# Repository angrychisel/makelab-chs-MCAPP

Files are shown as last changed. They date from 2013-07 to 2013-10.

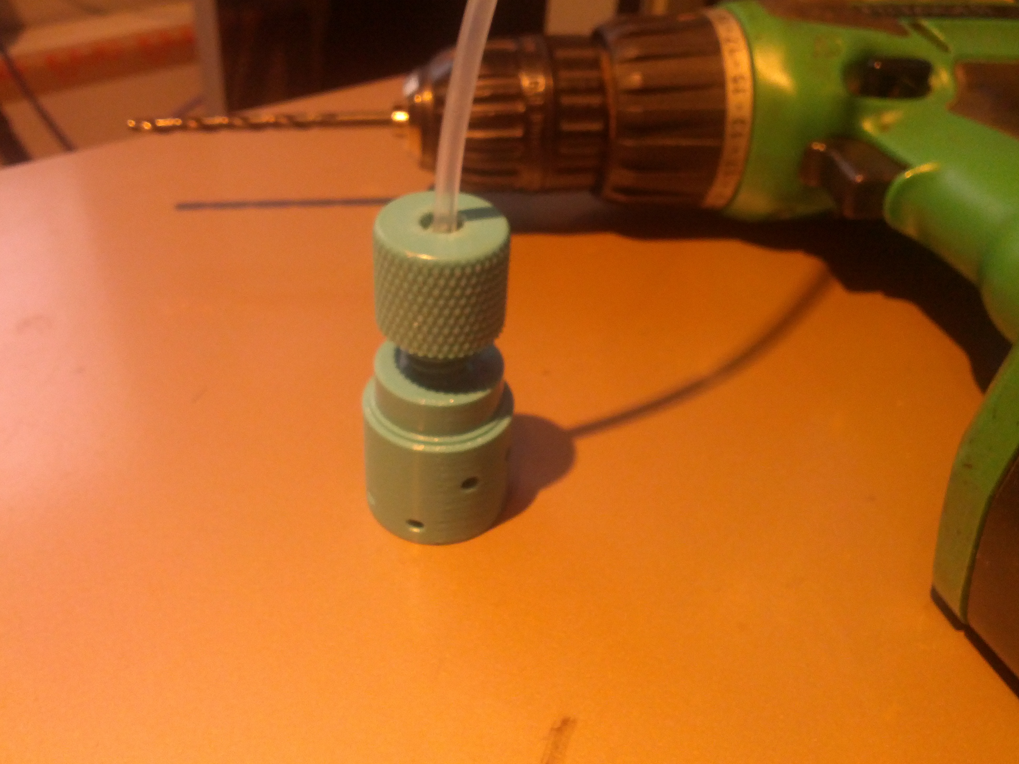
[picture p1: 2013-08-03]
MORGAN/IMAGES/2013-07-31 16.58.30.jpg

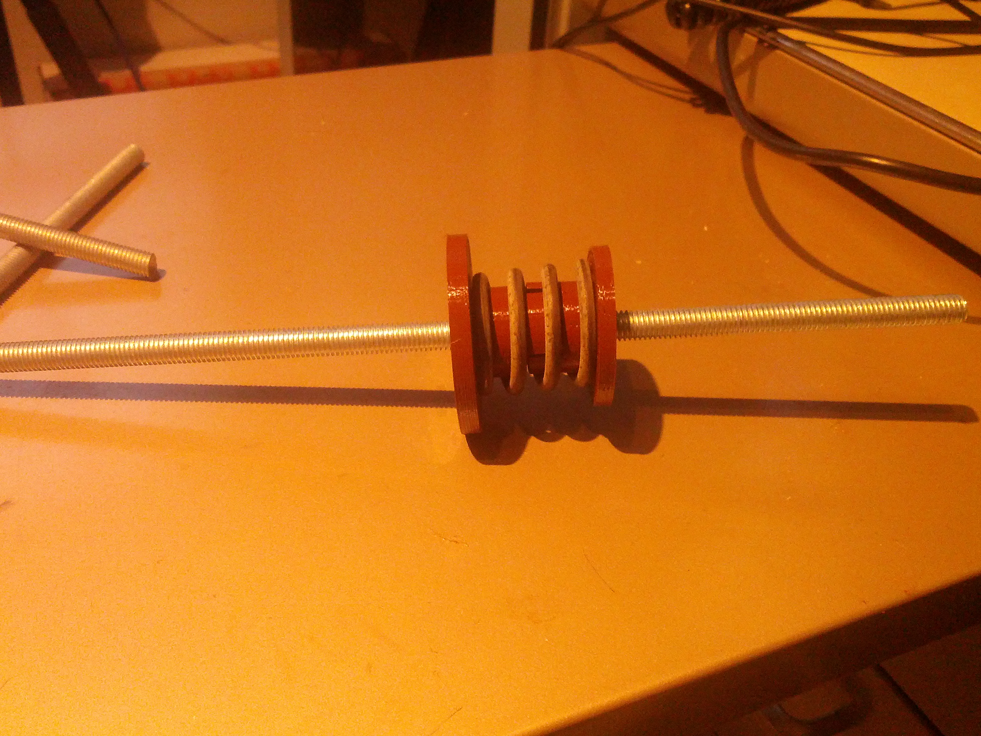
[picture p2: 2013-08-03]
MORGAN/IMAGES/2013-07-31 17.22.46.jpg

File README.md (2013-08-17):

Visit our IRC channel (http://makelabcharleston.org/)

MCAPP - The Makelab Charleston Affordable 3d Printer Project
----------------------

[[Github Page](http://angrychisel.github.io/makelab-chs-MCAPP/)]

**Join our IRC Channel**

Visit our IRC channel (https://kiwiirc.com/client/irc.freenode.net/?nick=morgan|?#makelabcharleston)

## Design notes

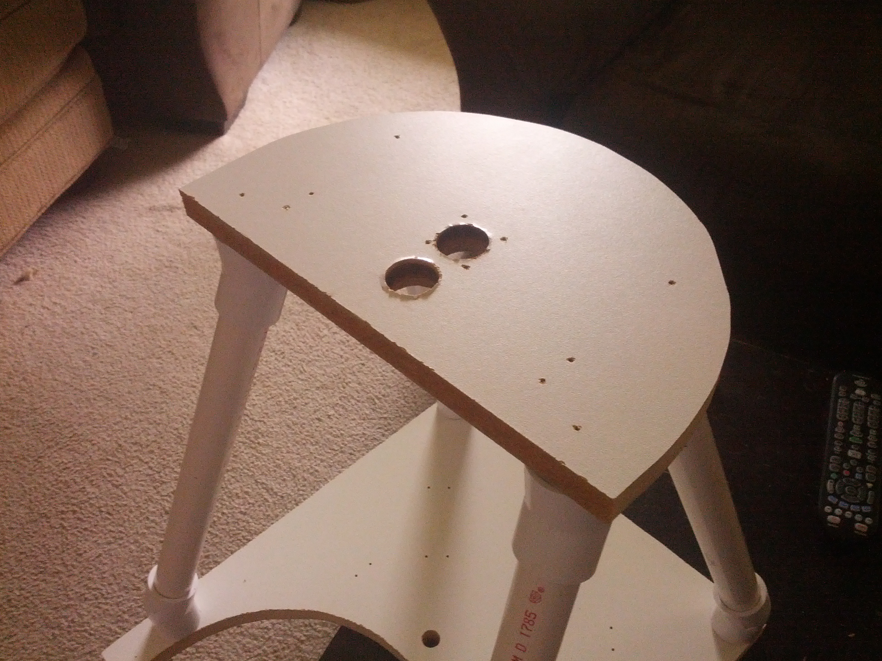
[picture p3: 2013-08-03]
MORGAN/IMAGES/2013-08-03 15.07.26.jpg

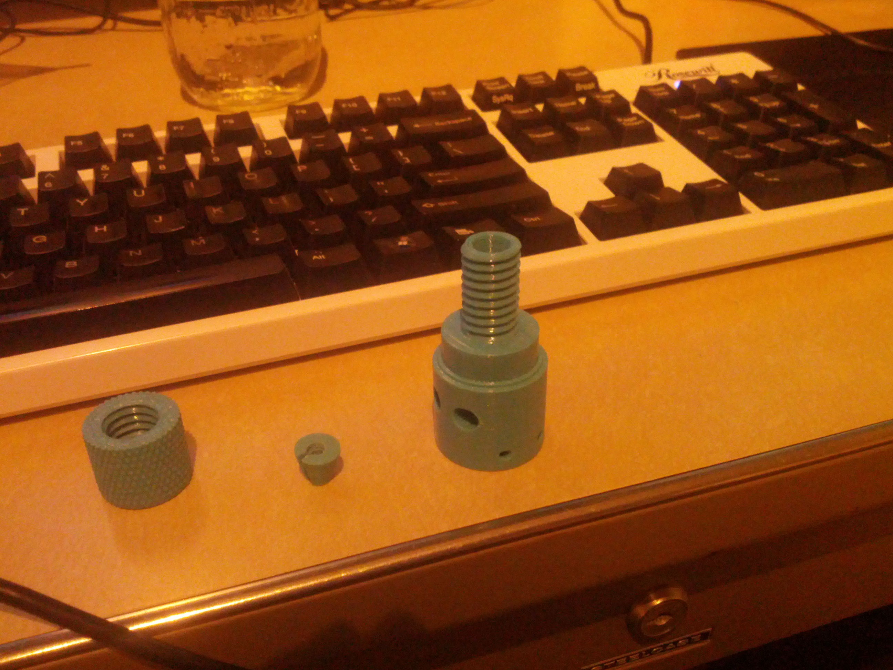
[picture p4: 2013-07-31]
MORGAN/IMAGES/2013-07-30 22.39.01.jpg

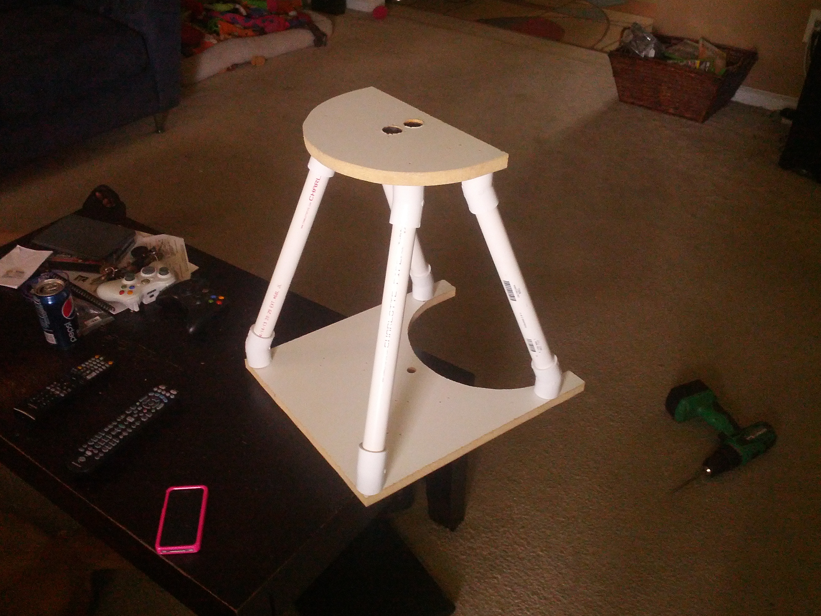
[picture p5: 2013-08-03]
MORGAN/IMAGES/2013-08-03 15.07.51.jpg

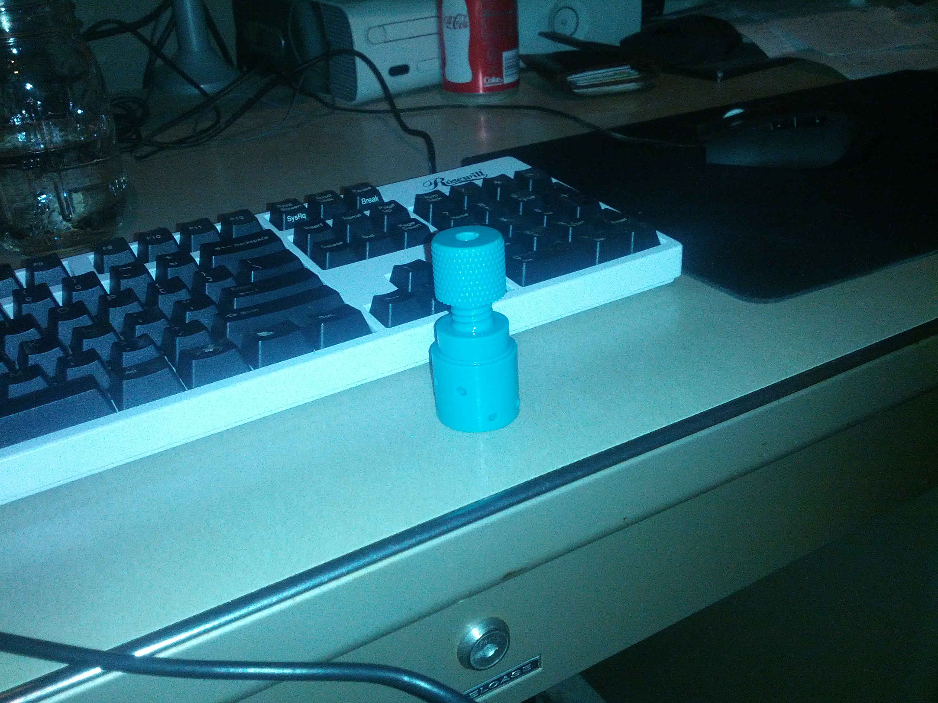
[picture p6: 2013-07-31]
MORGAN/IMAGES/2013-07-30 22.37.41.jpg

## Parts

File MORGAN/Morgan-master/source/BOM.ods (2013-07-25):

Component | Quantity
01-pvc_pipe_support_a | 4
02-pvc_pipe_support_b | 4
03-z_mount_bottom_8mm | 1
04-z_mount_top_8mm | 1
05-motormount_short | 1
06-motormount_tall | 1
07-drivewheel_rod | 1
08-drivewheel_tube | 1
09-22mm_6805_bearing_adaptor | 1
10-bed_arm_left_8mm | 1
11-bed_arm_right_8mm | 1
12-bed_z_mount_bracket | 1
13-bed_rear_mountclips | 2
15mm pipe holders – To be done | 2
15-hall_endstop_holder | 3
16-leadscrew_shaft_motor_mount | 1
17-Morgan_arm_PSI_a | 1
18-Morgan_arm_PSI_b | 1
19-Morgan_arm_Theta_a | 1
20-Morgan_arm_Theta_b | 1
21-Morgan_toolhead | 1
22-Leadscrew-nut_Alpen8mmSDS | 1
23-extruder_bowden_adaptor | 1
Cap_2 | 2
Eckstruder_Big_Gear_Herringbone | 1
Eckstruder_Block_for_Prusa | 1
Eckstruder_Idler_Block_for_Prusa | 1
Eckstruder_Small_Gear_Herrinbone | 1
thumb_knob_M4_extruder | 1
TighteningCone_2 | 2
M8 nut | 12
M8 washer | 6
M8 spring washer | 10
M8 washer 28mm | 6
M4 nut | 9
M4 bolt 40mm | 8
M4 bolt 80mm | 1
M8 Nylock Nut | 6
M8 Bolt 40mm | 3
M8 Bolt 100mm | 1
M8 Bolt 60mm | 1
PVC pipe 32mm OD 459mm | 2
PVC pipe 32mm OD 452mm | 2
2mm self tapping coach screws, 40mm | 2
15mm brass pipe 440mm | 1
15mm brass pipe 200mm | 2
22mm brass pipe 460mm | 1
8mm threaded rod 650mm | 1
8mm smooth rod | 2
608z | 5
F608z | 4
hard spring (idler compression) 7mm | 1
8mm soft spring (lead screw anti backlash | 1
cabinet coach screws, 5mm | 10
LM8uu bearing or alternative | 4
lead screw 330mm | 1
M3 nut | 3
M3 grub screw 6mm (or suitable replacement bolt | 3
hall effect endstop sensors | 3
Electronics | 1
Pololu low current 1/16th | 2
Pololu high current 1/32th | 2
Step motor 200step (1.8deg) | 2
Step motor 400step (0.9deg (if possible – otherwise increase other motors) | 2
Power supply AXT 400W minimum | 1
PTFE tube 6mm 600mm | 1
Additional PTFE tube 4mm 600mm (Only if 1.75mm J-head) | 1
Morgan lasercut platforms | 1
Universal build plate | 1
Mk2a heatbed | 1
aluminium build surface | 1
Ethernet cable, multistrand flexible, m | 5
High current cable, heatbed m | 1

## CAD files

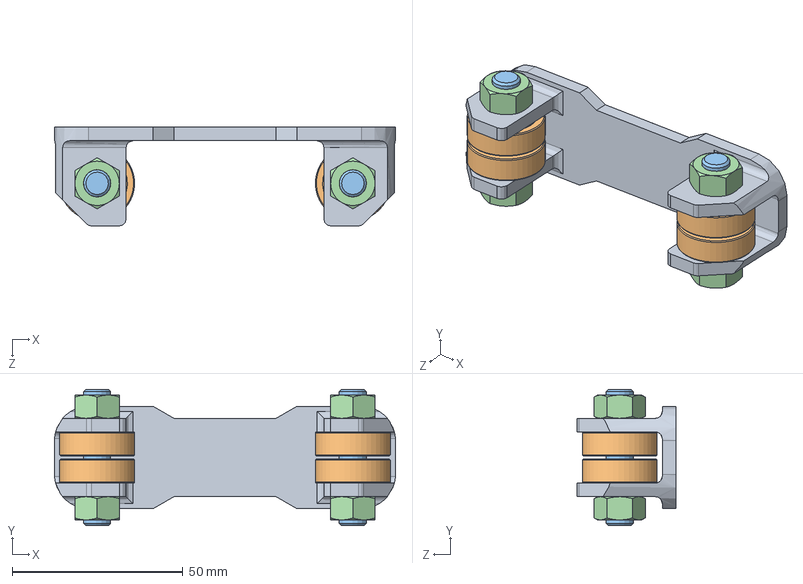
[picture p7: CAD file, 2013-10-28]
MORGAN/ACCESSORIES/SPOOL ROLLER ASSY.SLDASM
100.0 x 40.0 x 29.0 mm
SPOOL ROLLER
radial ball bearing_68_am x 4
continous stud_am x 2
hex nut style 1_am x 4

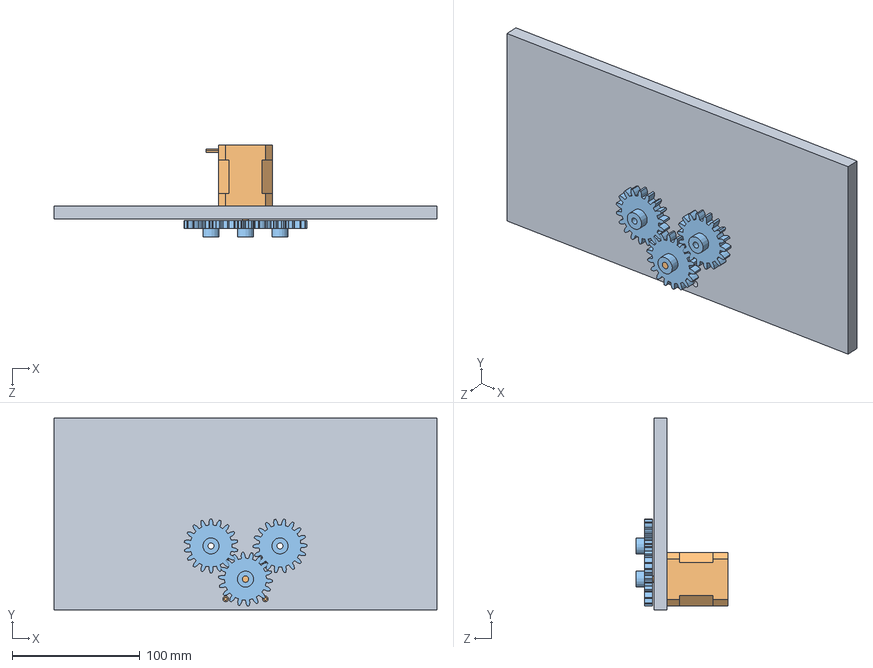
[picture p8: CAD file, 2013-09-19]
MORGAN/good extruder/good extruder assy.SLDASM
300.0 x 150.0 x 71.8 mm
main plate
NEMA17STEPPER
spur gear_ai x 3
radial ball bearing_68_am x 2

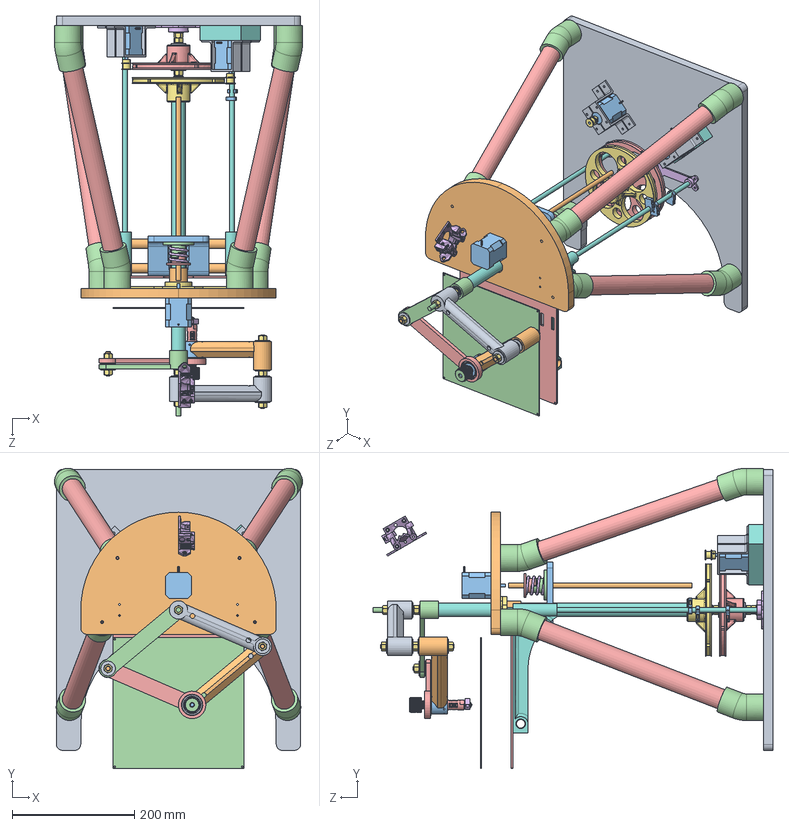
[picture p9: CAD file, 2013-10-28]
MORGAN/MLC-1.SLDASM
406.1 x 491.9 x 655.0 mm
MLC-1-001
MLC-1-002
NEMA17STEPPER x 3
4880K703 x 8
MLC-1-004 x 4
MLC-1-005
MLC-1-006
MLC-1-0012 x 2
LM8UU x 4
MLC-1-0015 x 3
MLC-1-0021
MLCE-1-001
MLCE-1-002
9662K350
hex nut style 1_am x 2
MLC-1-0014 x 2
radial ball bearing_68_skf x 8
MLC-1-0022
MLC-1-0025 x 8
MLC-1-008
MLC-1-0010
MLC-1-0026
MLC-1-009
MLC-1-007
MLC-1-0016
MLC-1-0017
MLC-1-0018
MLC-1-0019
MLC-1-0020
curved spring lock washer_din x 6
hex nut gradec_din x 22
plain washer 6902 type abc_din x 5
plain washer large_din x 9
continous stud_am x 2
socket head cap screw_am x 2
MLC-1-030
JHEAD
JHEAD NOZZLE
pulley 20t gt2 2mm x 2
MLC-1-0027
MLC-1-0028 x 4
MLC-1-0029
hall_effect_sensor_holder x 3
MK2A Heatbed
HEATBED BASE PLATE
airtripper-extruder-v3

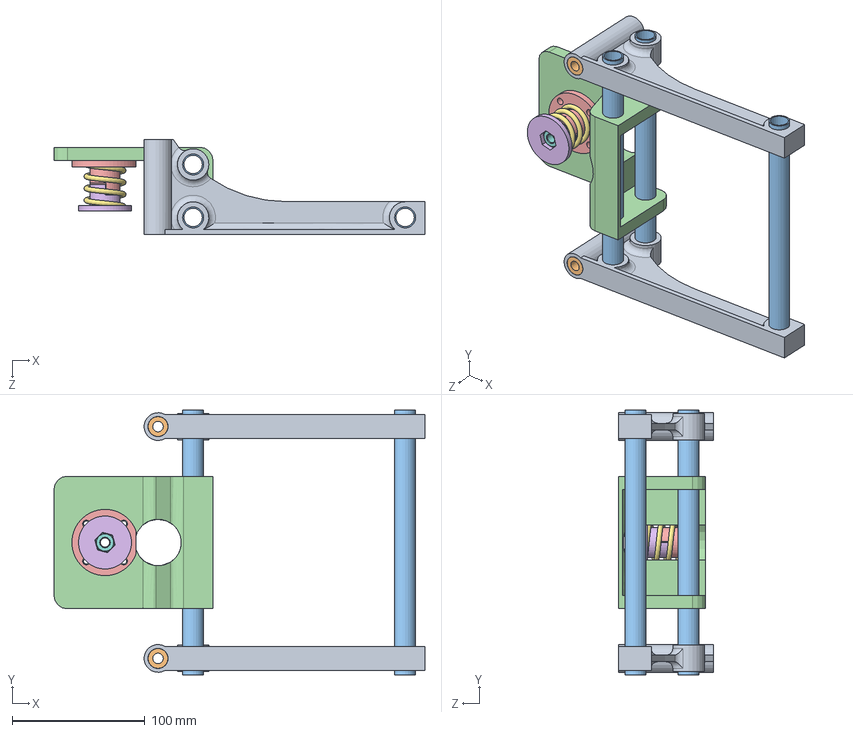
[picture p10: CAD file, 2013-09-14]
MORGAN/MLC-3.SLDASM
280.0 x 200.0 x 72.0 mm
MLC-1-0012 x 2
LM8UU x 4
MLC-1-0015 x 3
MLC-1-0021
MLCE-1-001
MLCE-1-002
9662K350
hex nut style 1_am x 2

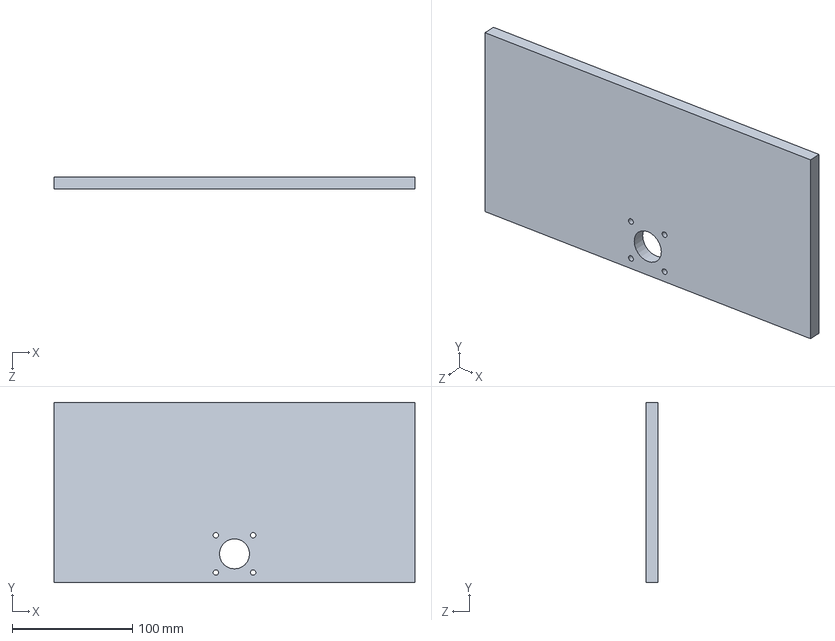
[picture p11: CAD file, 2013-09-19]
MORGAN/good extruder/main plate.SLDPRT
300.0 x 150.0 x 10.0 mm

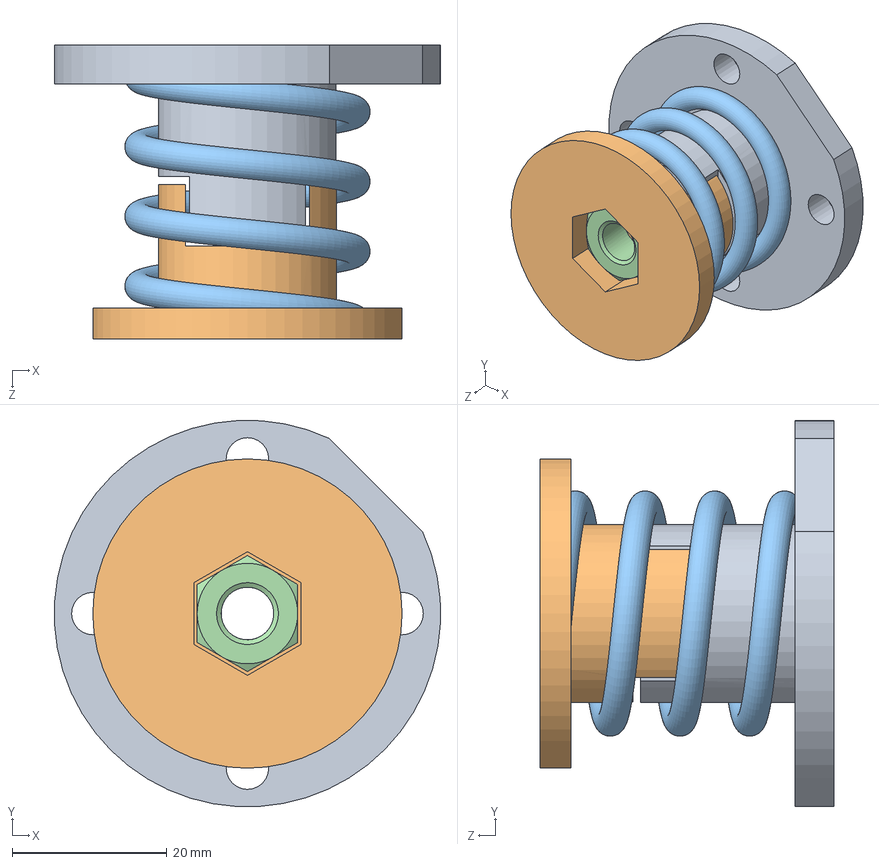
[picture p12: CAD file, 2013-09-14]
MORGAN/EXPERIMENTAL/MLCE-50.SLDASM
49.9 x 49.9 x 38.0 mm
MLCE-1-001
MLCE-1-002
9662K350
hex nut style 1_am x 2

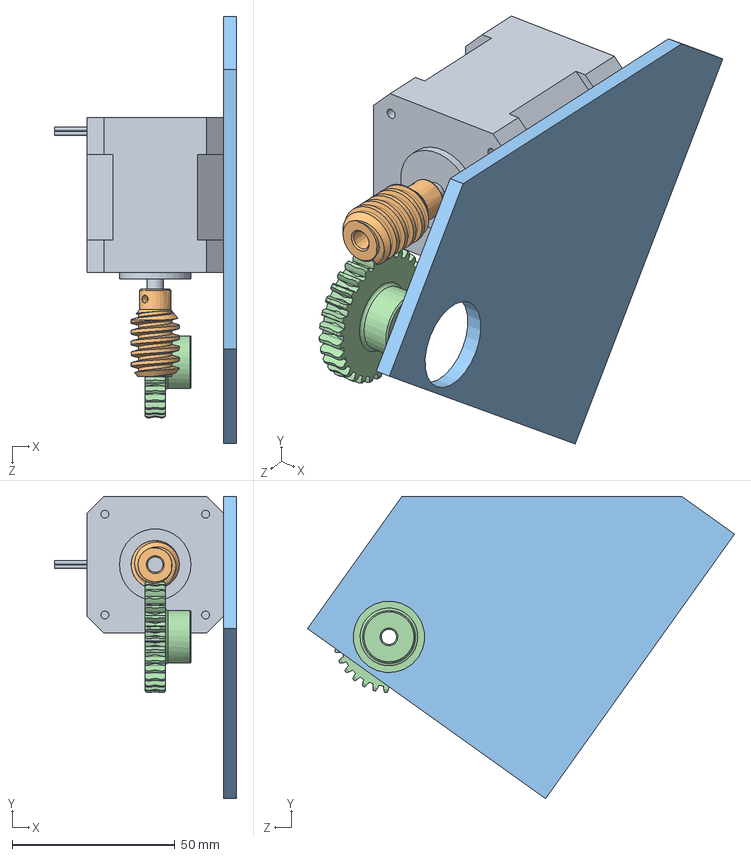
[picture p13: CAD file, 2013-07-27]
MORGAN/WORM EXTRUDER/MLCEX-1.SLDASM
56.0 x 93.0 x 131.4 mm
NEMA17STEPPER
LUHB
STEPPER BASE
g1035

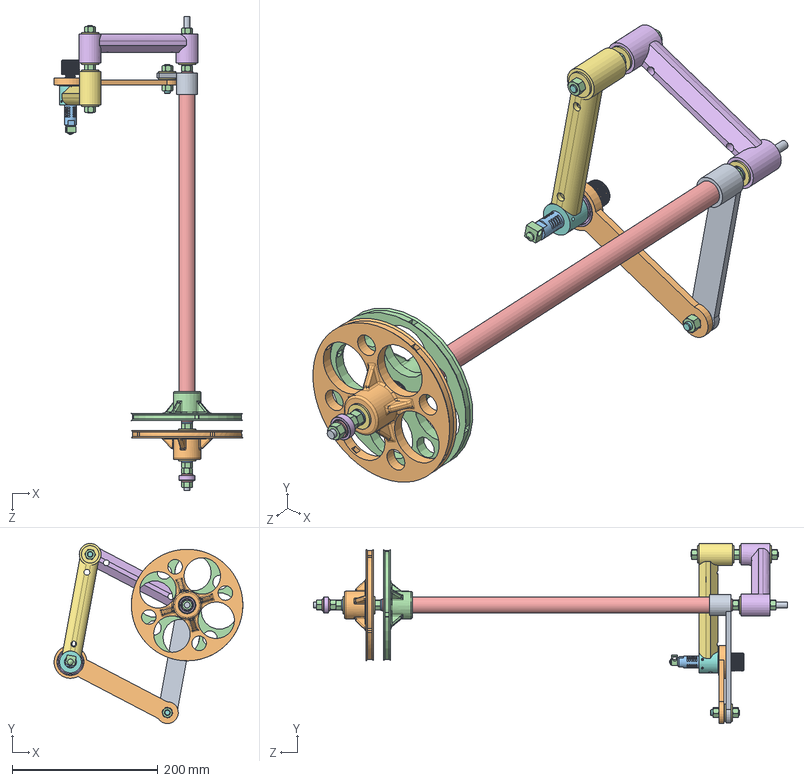
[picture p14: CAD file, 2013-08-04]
MORGAN/MLC-6.SLDASM
258.9 x 247.0 x 650.0 mm
MLC-1-008
MLC-1-0010
MLC-1-0026
MLC-1-009
MLC-1-007
MLC-1-0016
MLC-1-0017
MLC-1-0018
MLC-1-0019
MLC-1-0020
curved spring lock washer_din x 6
hex nut gradec_din x 22
plain washer 6902 type abc_din x 5
radial ball bearing_68_skf x 7
plain washer large_din x 9
continous stud_am x 2
socket head cap screw_am x 2
MLC-1-030
JHEAD
JHEAD NOZZLE

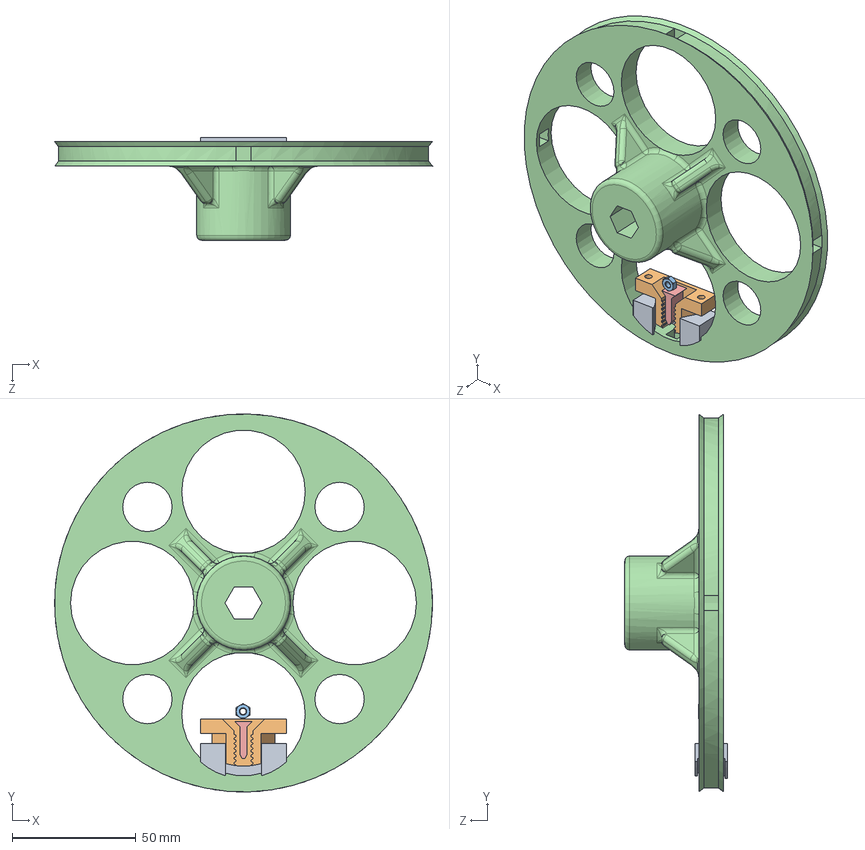
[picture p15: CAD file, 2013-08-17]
MORGAN/EXPERIMENTAL/belt tenisoner.SLDASM
153.0 x 152.9 x 41.5 mm
belt tensioner bottom
belt tensioner
hex nut style 1_am
MLC-1-0010
belt stop

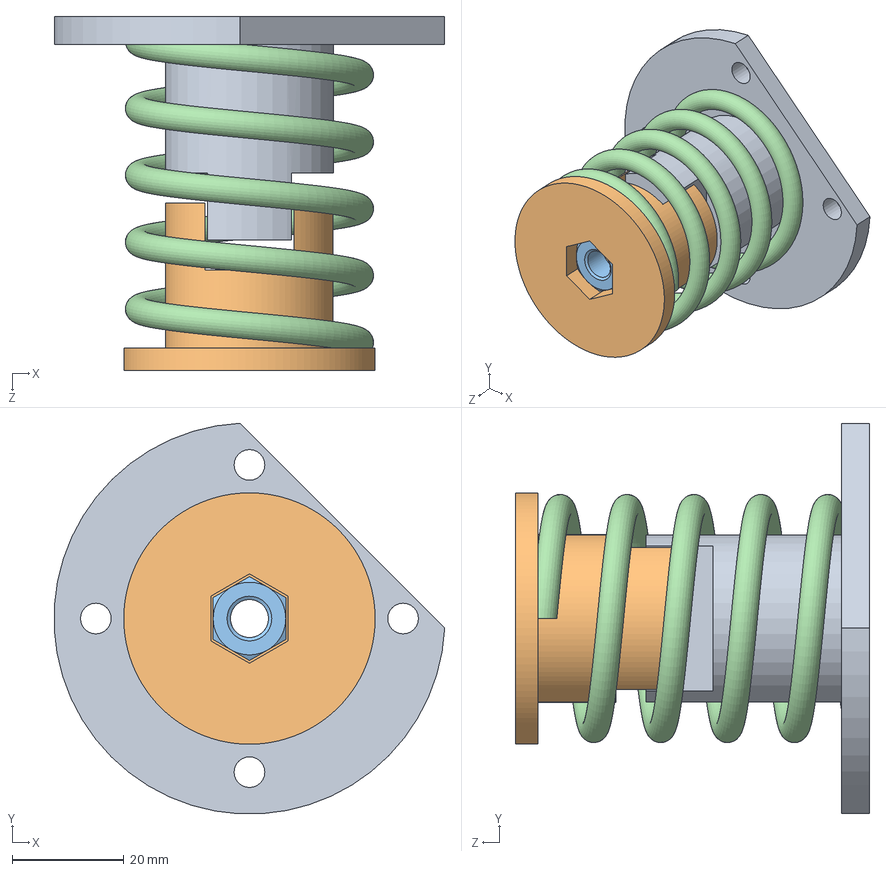
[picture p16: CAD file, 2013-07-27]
MORGAN/EXPERIMENTAL/MLC-5.SLDASM
69.9 x 69.9 x 63.4 mm
MLC-1-024
MLC-1-023
hex nut style 1_am x 2
9662K480

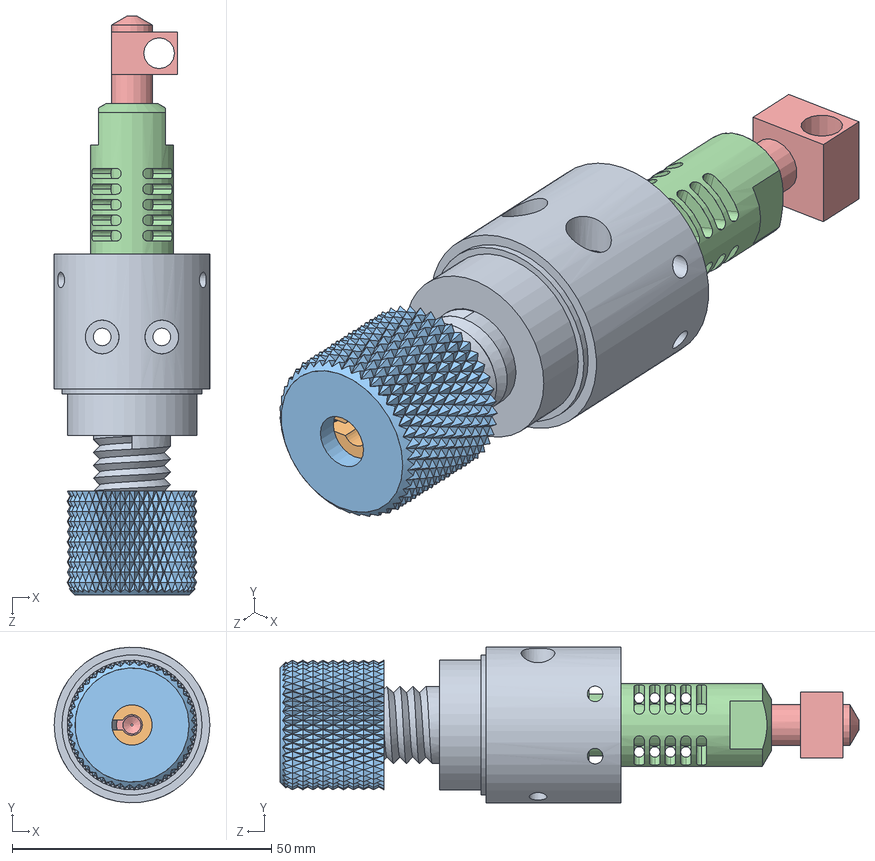
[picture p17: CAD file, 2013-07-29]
MORGAN/MLC-7.SLDASM
30.0 x 30.0 x 111.6 mm
MLC-1-0018
MLC-1-031
MLC-1-030
JHEAD
JHEAD NOZZLE

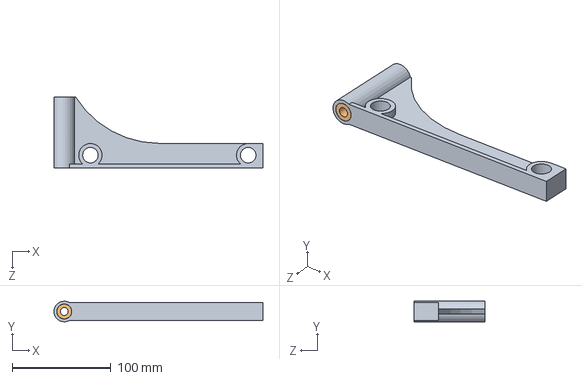
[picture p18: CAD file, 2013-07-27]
MORGAN/MLC-2.SLDASM
211.9 x 21.0 x 72.0 mm
MLC-1-0012
LM8UU x 2

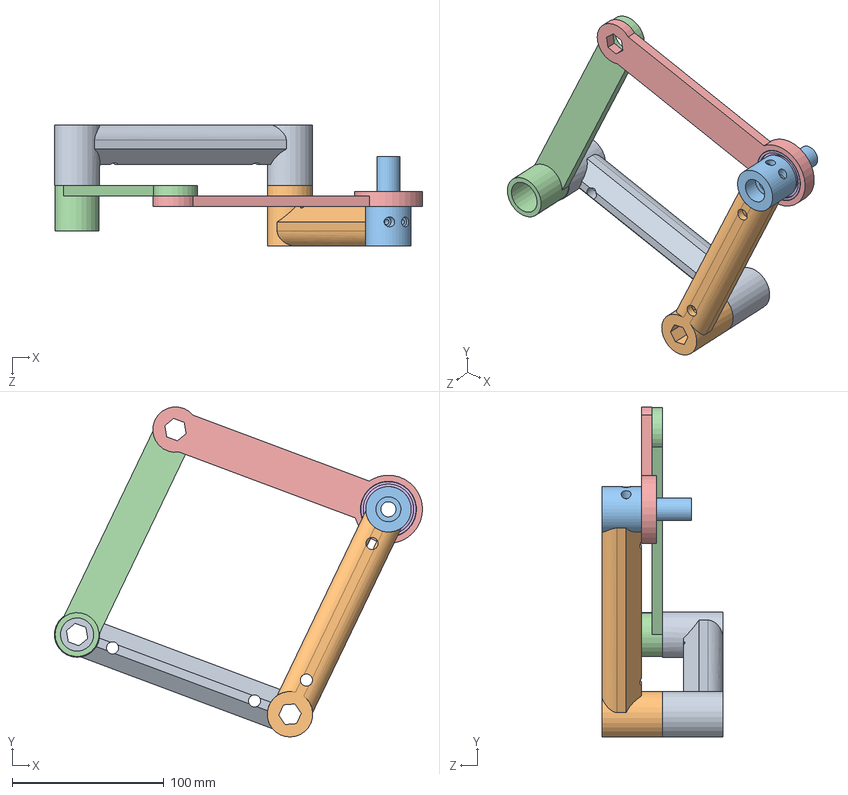
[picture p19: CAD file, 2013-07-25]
MORGAN/MLC-4.SLDASM
242.8 x 217.7 x 80.0 mm
MLC-1-0016
MLC-1-0017
MLC-1-0018
MLC-1-0019
MLC-1-0020
radial ball bearing_68_skf

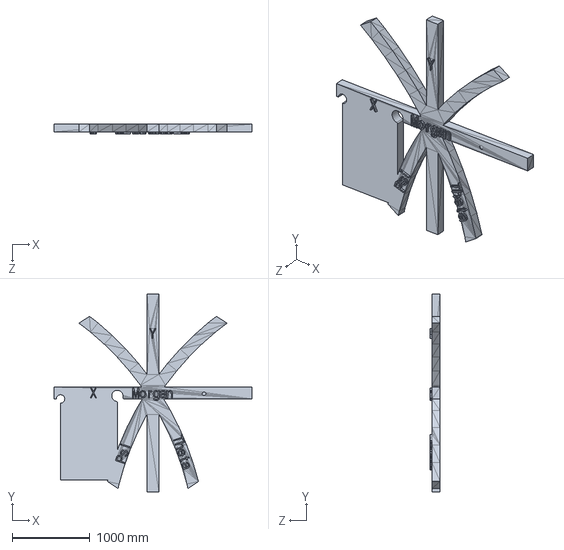
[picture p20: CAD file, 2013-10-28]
MORGAN/EXPERIMENTAL/SCARA-CAL.SLDPRT
2540.0 x 2540.0 x 127.0 mm

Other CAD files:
MORGAN/FAB APPROVED STL/MLC-1-0029.STL
MORGAN/Morgan-master/dxf/UNIVERSAL PLATE.SLDPRT
MORGAN/Morgan-master/source/Base_and_Riser_2.stl
MORGAN/Morgan-master/stl/NEMA17STEPPER.SLDPRT
MORGAN/EXPERIMENTAL/SCARA-CAL.scad
MORGAN/Morgan-master/source/Reprap_Morgan-v1.00.scad
MORGAN/4880K330.SLDPRT
MORGAN/4880K703.SLDPRT
MORGAN/ACCESSORIES/SPOOL ROLLER.SLDPRT
MORGAN/ACCESSORIES/SPOOL ROLLER.STL
MORGAN/EXPERIMENTAL/50mm riser-short.SLDPRT
MORGAN/EXPERIMENTAL/50mm riser.SLDPRT
MORGAN/EXPERIMENTAL/9662K350.SLDPRT
MORGAN/EXPERIMENTAL/9662K480.SLDPRT
MORGAN/EXPERIMENTAL/HEATBED BASE PLATE.DXF
MORGAN/EXPERIMENTAL/HEATBED BASE PLATE.SLDDRW
MORGAN/EXPERIMENTAL/HEATBED BASE PLATE.SLDPRT
MORGAN/EXPERIMENTAL/MLC-1-023.SLDPRT
MORGAN/EXPERIMENTAL/MLC-1-023.STL
MORGAN/EXPERIMENTAL/MLC-1-024.SLDPRT
MORGAN/EXPERIMENTAL/MLC-1-024.STL
MORGAN/EXPERIMENTAL/MLCE-1-001.SLDDRW
MORGAN/EXPERIMENTAL/MLCE-1-001.SLDPRT
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

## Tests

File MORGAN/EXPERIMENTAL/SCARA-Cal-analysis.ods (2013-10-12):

Dimension | Measurement | Target | Current Step/deg | Scaling Factor | New Step M92 | New factor M365 | after scaling
Theta | 100 | 100.000 | 450 |  | 450 | 1 | 100.000
Psi | 100 | 100.000 | 450 |  | 450 | 1 | 100.000
X | 100 | 100.000 |  | 1 |  | 1 | 100.000
Y | 100 | 100.000 |  | 1 |  | 1 | 100.000
Z

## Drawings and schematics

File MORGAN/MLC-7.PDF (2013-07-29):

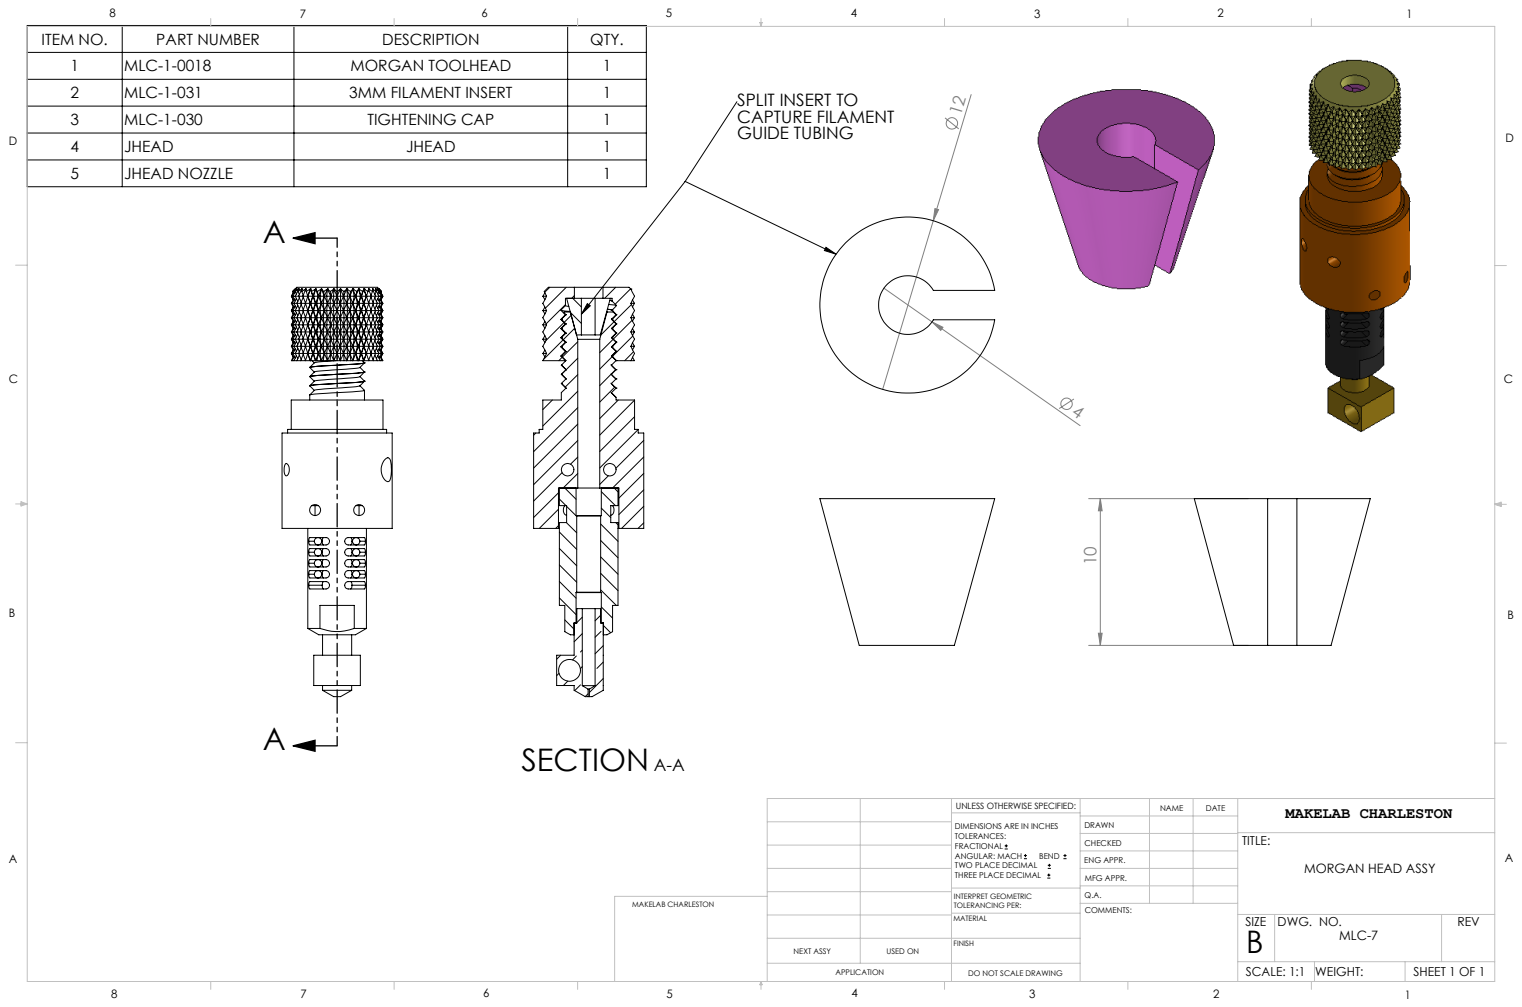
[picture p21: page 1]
SECTION A-A; MAKELAB CHARLESTON; NEXT ASSY; USED ON; ANGULAR: MACH; BEND; INTERPRET GEOMETRIC TOLERANCING PER:; ENG APPR.; MFG APPR.; NAME; DATE; DWG. NO.; REV; SCALE: 1:1 WEIGHT:; SHEET 1 OF 1

ITEM NO. | PART NUMBER | DESCRIPTION | QTY.
1 | MLC-1-0018 | MORGAN TOOLHEAD | 1
2 | MLC-1-031 | 3MM FILAMENT INSERT | 1
3 | MLC-1-030 | TIGHTENING CAP | 1
4 | JHEAD | JHEAD | 1
5 | JHEAD NOZZLE | | 1

SPLIT INSERT TO
CAPTURE FILAMENT
GUIDE TUBING

UNLESS OTHERWISE SPECIFIED:

DIMENSIONS ARE IN INCHES
TOLERANCES:
FRACTIONAL
TWO PLACE DECIMAL
THREE PLACE DECIMAL

MORGAN HEAD ASSY

DO NOT SCALE DRAWING

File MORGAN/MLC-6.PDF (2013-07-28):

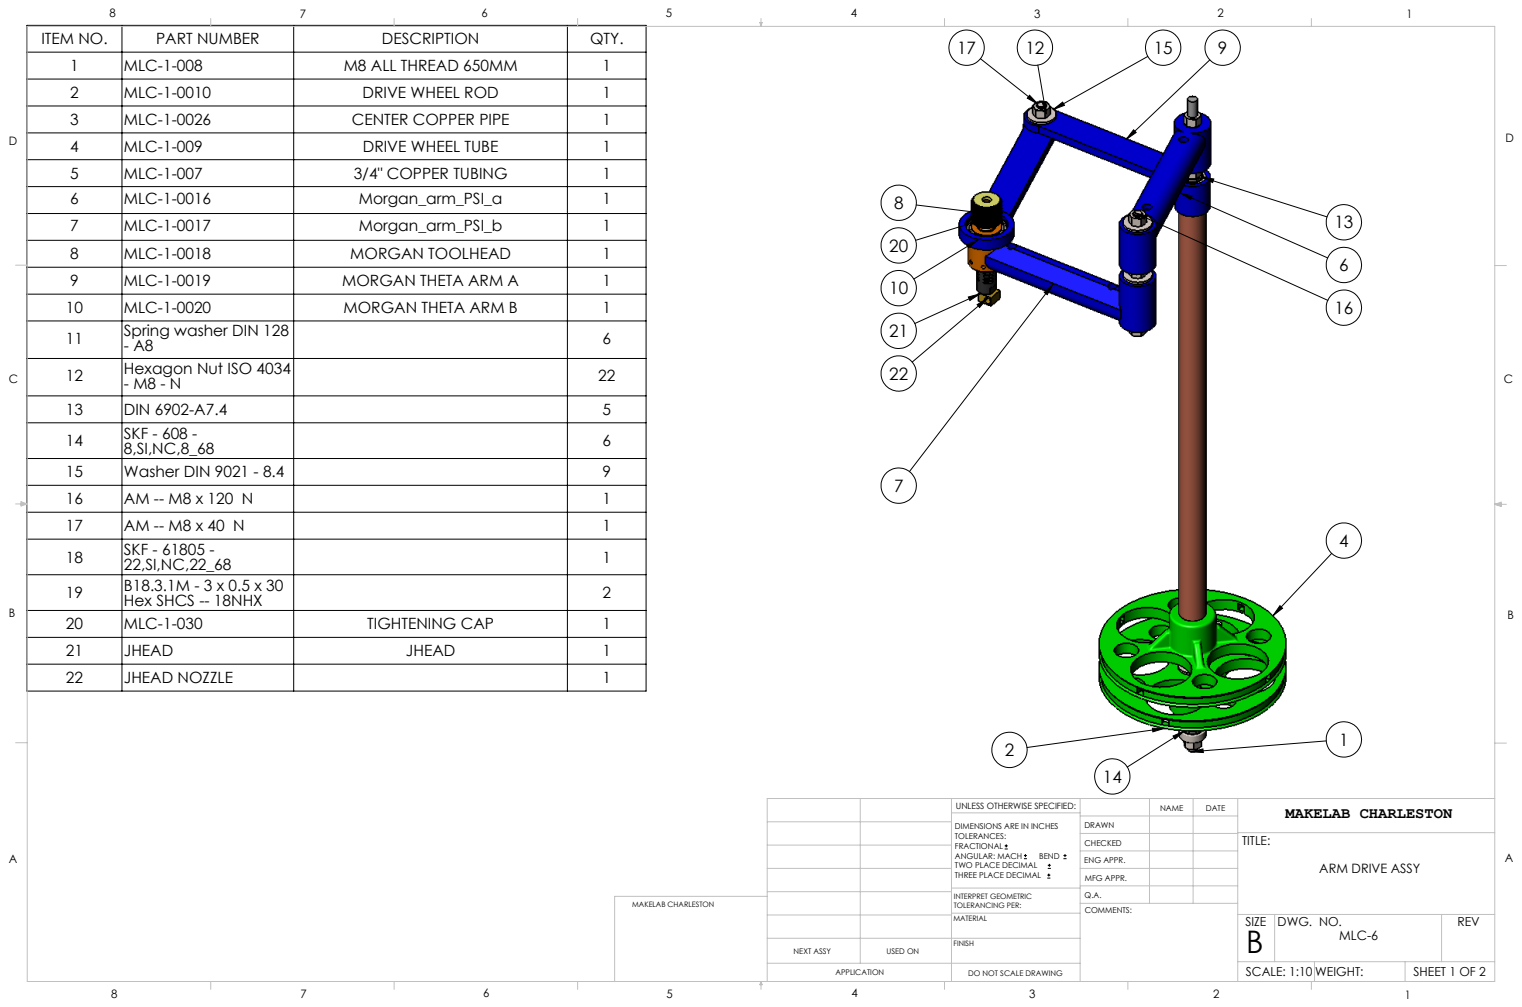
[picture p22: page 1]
MAKELAB CHARLESTON; NEXT ASSY; USED ON; ANGULAR: MACH; BEND; INTERPRET GEOMETRIC TOLERANCING PER:; ENG APPR.; MFG APPR.; NAME; DATE; DWG. NO.; REV; SCALE: 1:10 WEIGHT:; SHEET 1 OF 2

ITEM NO. | PART NUMBER | DESCRIPTION | QTY.
1 | MLC-1-008 | M8 ALL THREAD 650MM | 1
2 | MLC-1-0010 | DRIVE WHEEL ROD | 1
3 | MLC-1-0026 | CENTER COPPER PIPE | 1
4 | MLC-1-009 | DRIVE WHEEL TUBE | 1
5 | MLC-1-007 | 3/4" COPPER TUBING | 1
6 | MLC-1-0016 | Morgan_arm_PSI_a | 1
7 | MLC-1-0017 | Morgan_arm_PSI_b | 1
8 | MLC-1-0018 | MORGAN TOOLHEAD | 1
9 | MLC-1-0019 | MORGAN THETA ARM A | 1
10 | MLC-1-0020 | MORGAN THETA ARM B | 1
11 | Spring washer DIN 128 - A8 | | 6
12 | Hexagon Nut ISO 4034 - M8 - N | | 22

13 | DIN 6902-A7.4 | | 5
14 | SKF - 608 -8,SI,NC,8_68 | | 6
15 | Washer DIN 9021 - 8.4 | | 9
16 | AM -- M8 x 120 N | | 1
17 | AM -- M8 x 40 N | | 1
18 | SKF - 61805 -22,SI,NC,22_68 | | 1
19 | B18.3.1M - 3 x 0.5 x 30 Hex SHCS -- 18NHX | | 2
20 | MLC-1-030 | TIGHTENING CAP | 1
21 | JHEAD | JHEAD | 1
22 | JHEAD NOZZLE | | 1

UNLESS OTHERWISE SPECIFIED:

DIMENSIONS ARE IN INCHES
TOLERANCES:
FRACTIONAL
TWO PLACE DECIMAL
THREE PLACE DECIMAL

ARM DRIVE ASSY

DO NOT SCALE DRAWING

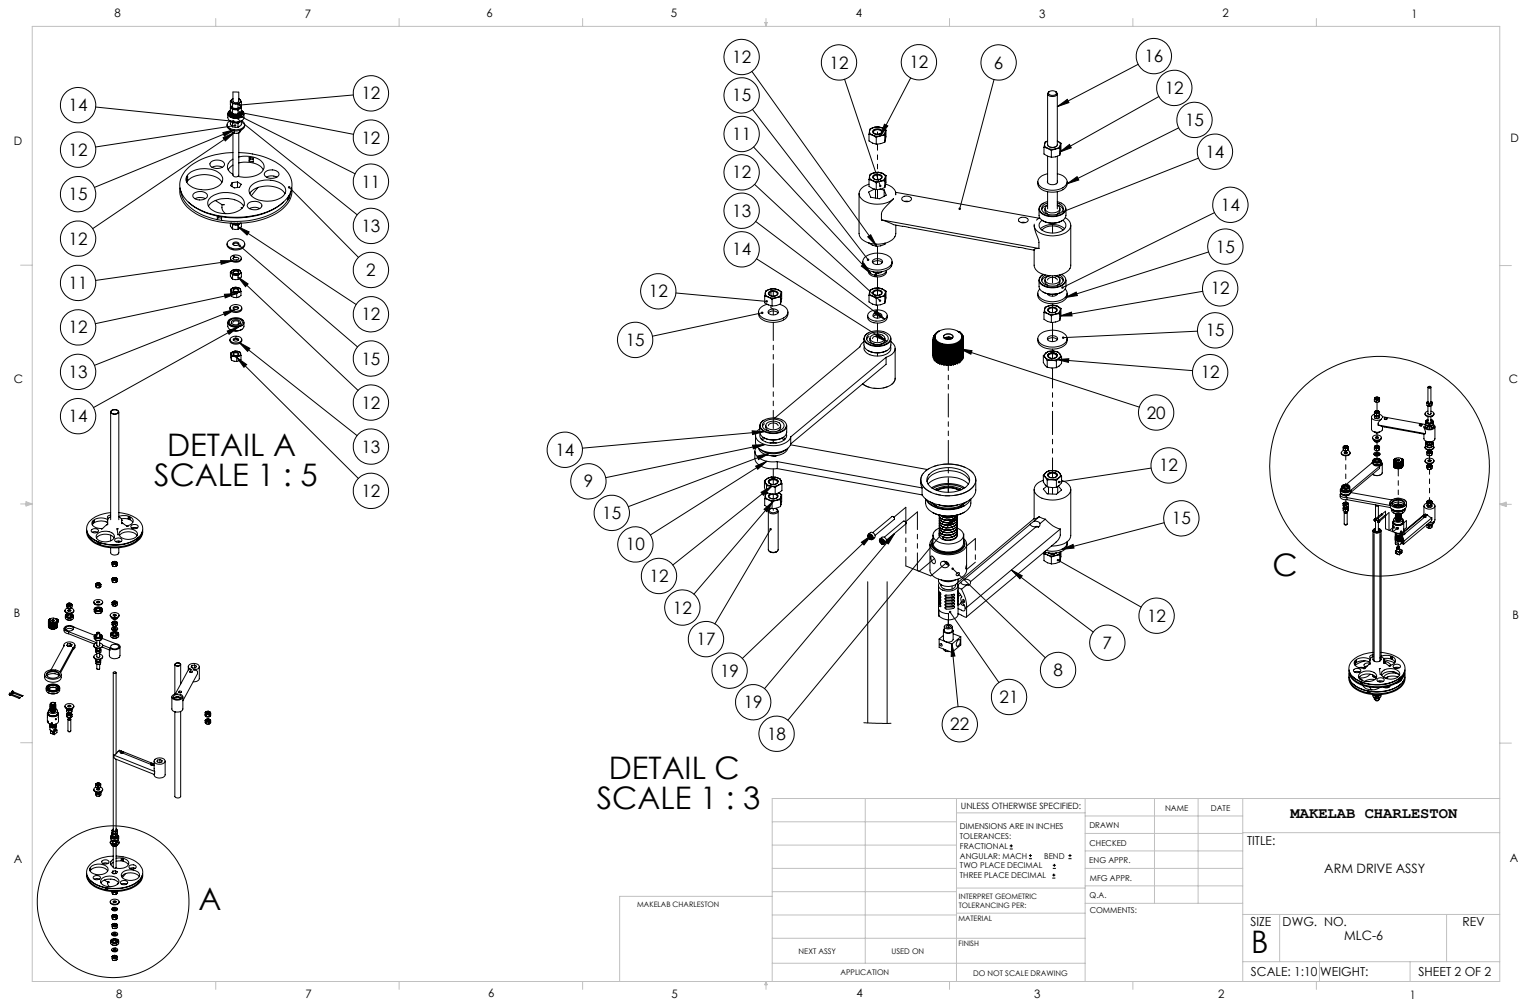
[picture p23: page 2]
DETAIL A SCALE 1 : 5; DETAIL C SCALE 1 : 3; MAKELAB CHARLESTON; NEXT ASSY; USED ON; ANGULAR: MACH; BEND; INTERPRET GEOMETRIC TOLERANCING PER:; ENG APPR.; MFG APPR.; NAME; DATE; SIZE B; DWG. NO.; REV; SCALE: 1:10 WEIGHT:; SHEET 2 OF 2

UNLESS OTHERWISE SPECIFIED:

DIMENSIONS ARE IN INCHES
TOLERANCES:
FRACTIONAL
TWO PLACE DECIMAL
THREE PLACE DECIMAL

ARM DRIVE ASSY

DO NOT SCALE DRAWING

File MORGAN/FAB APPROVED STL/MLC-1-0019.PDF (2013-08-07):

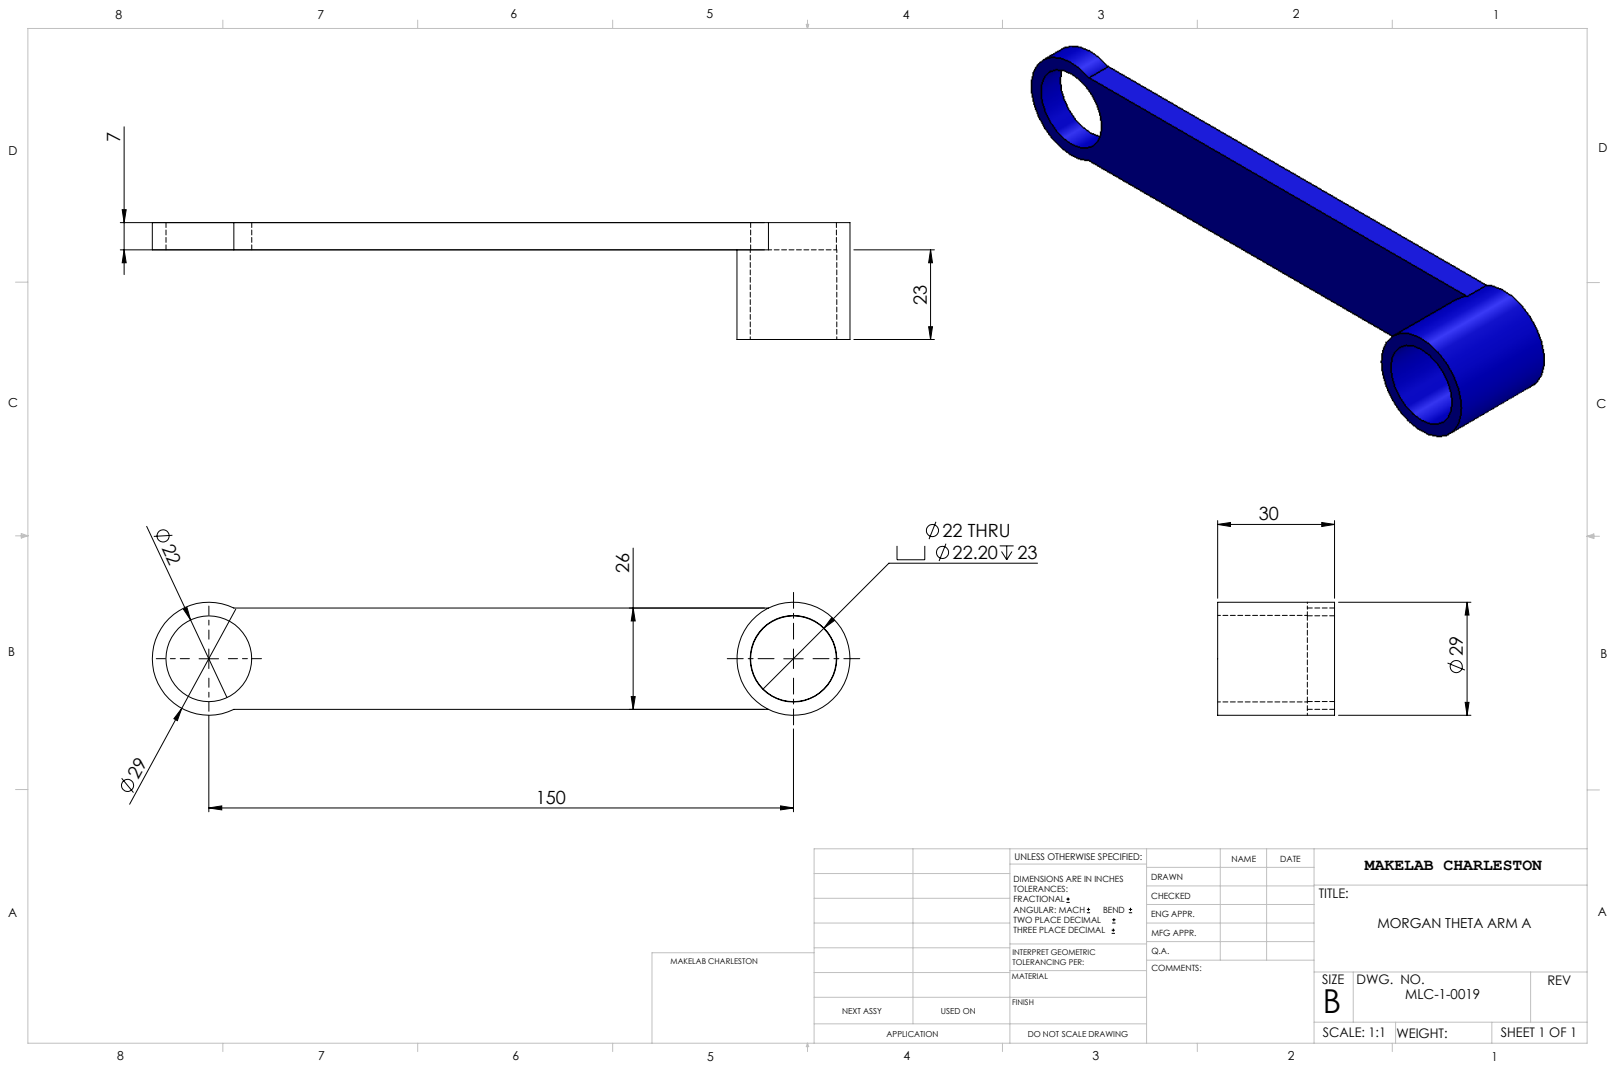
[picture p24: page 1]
22 THRU 22.20 23; MAKELAB CHARLESTON; NEXT ASSY; USED ON; ANGULAR: MACH; BEND; INTERPRET GEOMETRIC TOLERANCING PER:; ENG APPR.; MFG APPR.; NAME; DATE; DWG. NO.; REV; SCALE: 1:1 WEIGHT:; SHEET 1 OF 1

UNLESS OTHERWISE SPECIFIED:

DIMENSIONS ARE IN INCHES
TOLERANCES:
FRACTIONAL
TWO PLACE DECIMAL
THREE PLACE DECIMAL

MORGAN THETA ARM A

DO NOT SCALE DRAWING

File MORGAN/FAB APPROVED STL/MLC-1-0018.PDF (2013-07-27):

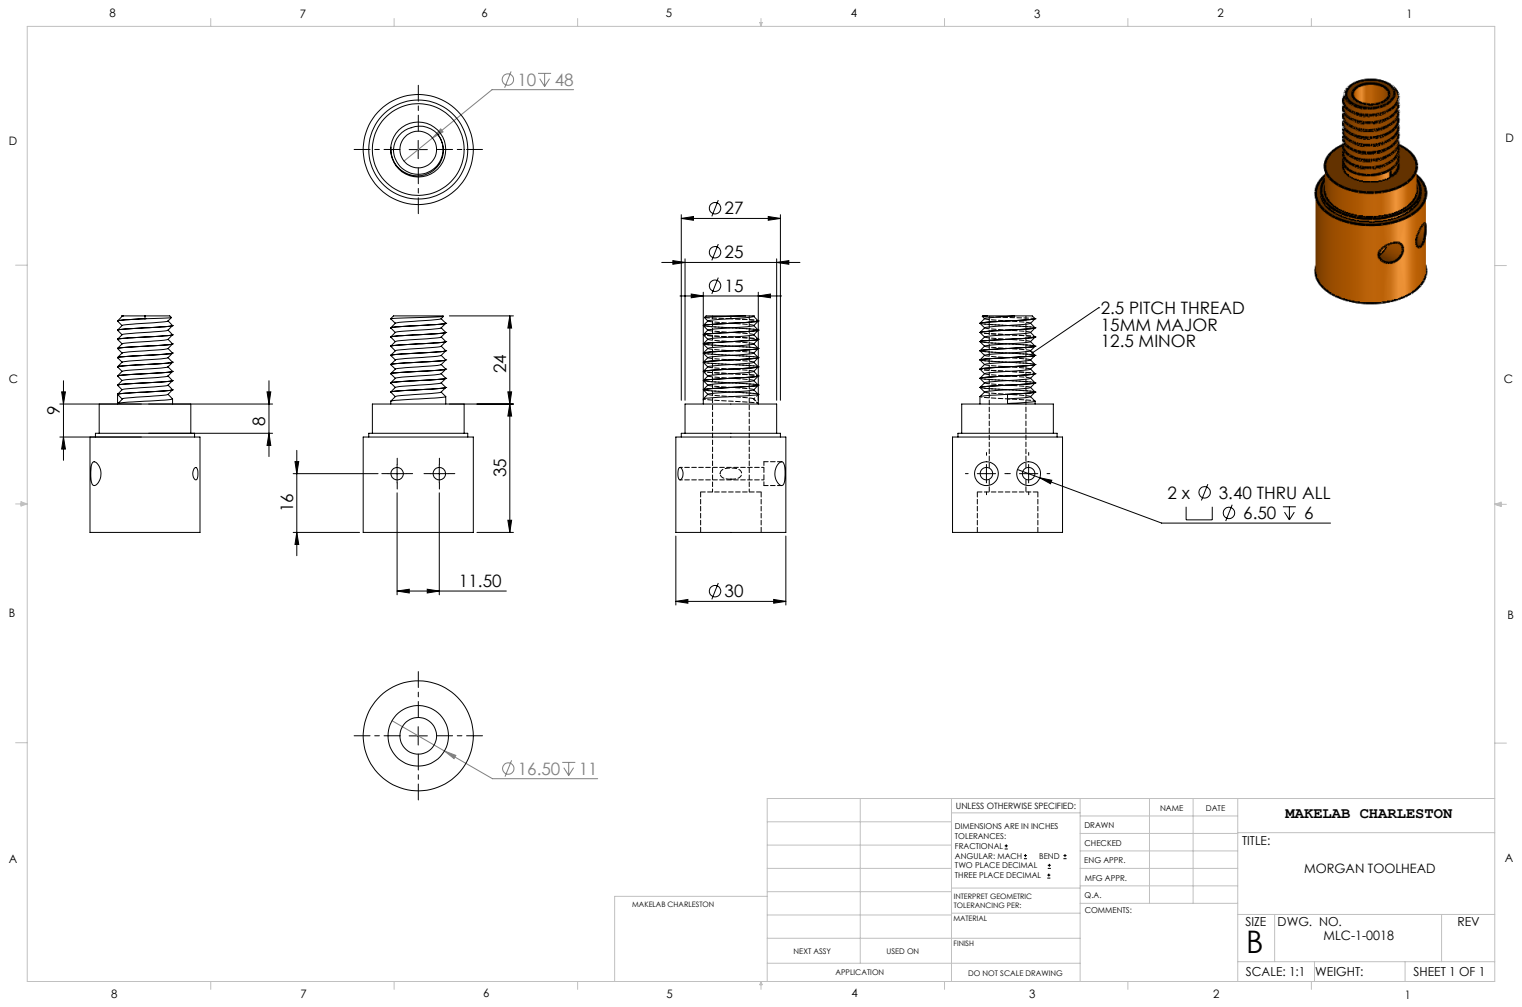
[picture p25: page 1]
3.40 THRU ALL; 2.5 PITCH THREAD 15MM MAJOR 12.5 MINOR; MAKELAB CHARLESTON; NEXT ASSY; USED ON; ANGULAR: MACH; BEND; INTERPRET GEOMETRIC TOLERANCING PER:; ENG APPR.; MFG APPR.; NAME; DATE; DWG. NO.; REV; SCALE: 1:1 WEIGHT:; MORGAN TOOLHEAD; SHEET 1 OF 1

UNLESS OTHERWISE SPECIFIED:

DIMENSIONS ARE IN INCHES
TOLERANCES:
FRACTIONAL
TWO PLACE DECIMAL
THREE PLACE DECIMAL

DO NOT SCALE DRAWING

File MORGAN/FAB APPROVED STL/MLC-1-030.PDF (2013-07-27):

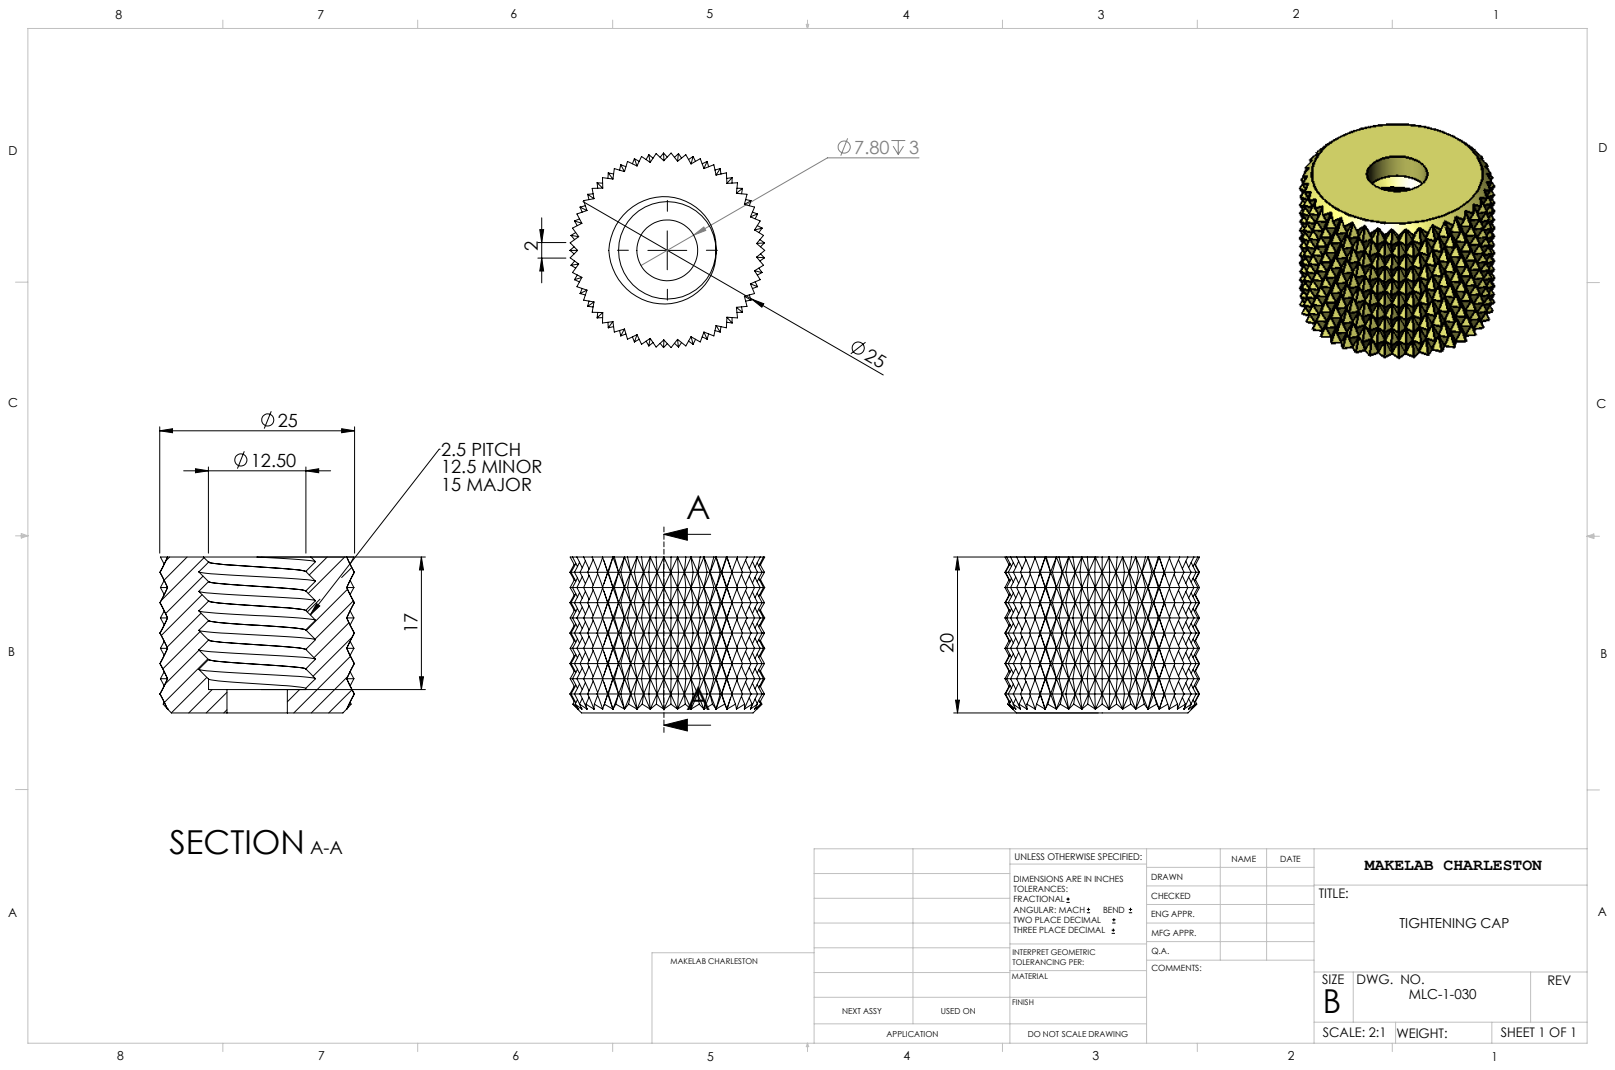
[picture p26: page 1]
SECTION A-A; 2.5 PITCH 12.5 MINOR 15 MAJOR; MAKELAB CHARLESTON; NEXT ASSY; USED ON; ANGULAR: MACH; BEND; INTERPRET GEOMETRIC TOLERANCING PER:; ENG APPR.; MFG APPR.; NAME; DATE; DWG. NO.; REV; SCALE: 2:1 WEIGHT:; TIGHTENING CAP; SHEET 1 OF 1

UNLESS OTHERWISE SPECIFIED:

DIMENSIONS ARE IN INCHES
TOLERANCES:
FRACTIONAL
TWO PLACE DECIMAL
THREE PLACE DECIMAL

DO NOT SCALE DRAWING

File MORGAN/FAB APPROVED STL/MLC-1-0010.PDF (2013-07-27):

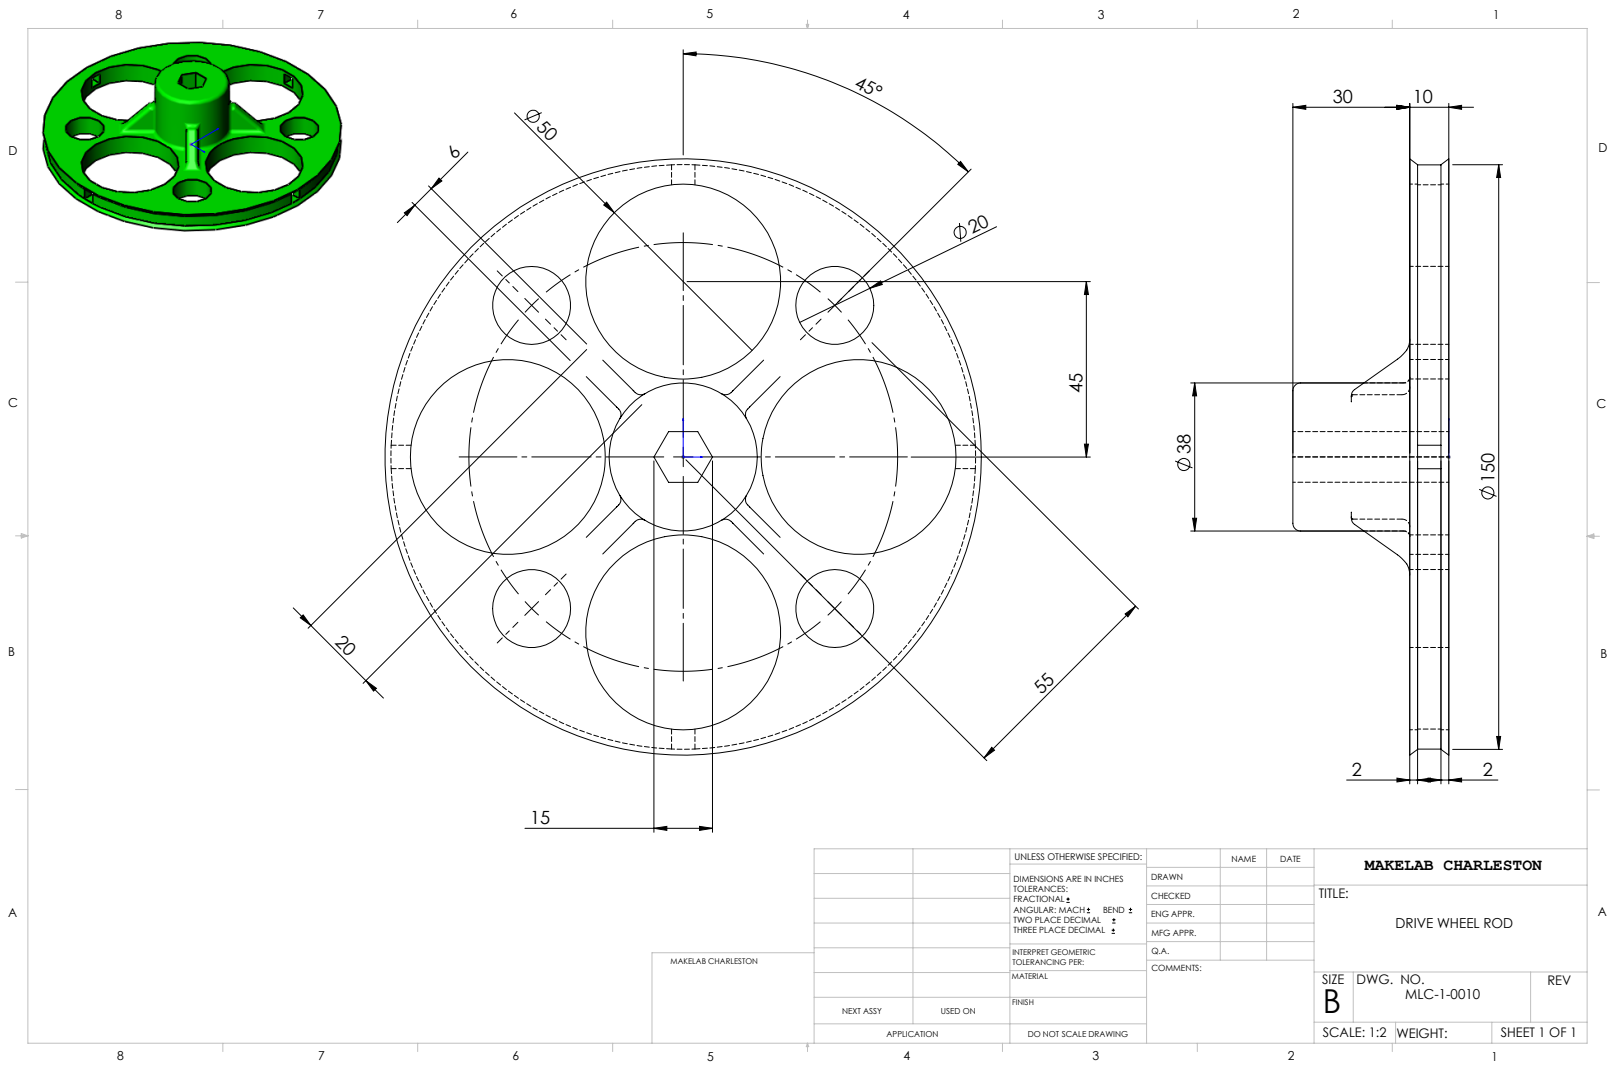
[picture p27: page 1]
MAKELAB CHARLESTON; NEXT ASSY; USED ON; ANGULAR: MACH; BEND; INTERPRET GEOMETRIC TOLERANCING PER:; ENG APPR.; MFG APPR.; NAME; DATE; DWG. NO.; REV; SCALE: 1:2 WEIGHT:; SHEET 1 OF 1

UNLESS OTHERWISE SPECIFIED:

DIMENSIONS ARE IN INCHES
TOLERANCES:
FRACTIONAL
TWO PLACE DECIMAL
THREE PLACE DECIMAL

DRIVE WHEEL ROD

DO NOT SCALE DRAWING

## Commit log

2013-07-25 Initial file upload
    uploaded Solidworks models for first time.
    [01-pvc_pipe_support_a.SLDPRT, 01-pvc_pipe_support_a.stl, 02-pvc_pipe_support_b.stl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]
2013-07-25 Uploaded assembly stl
    [MLC-1 - 4880K703-1.STL, MLC-1 - 4880K703-2.STL, MLC-1 - 4880K703-3.STL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]
2013-07-25 Revert "Uploaded assembly stl"
    This reverts commit 1989d028033d5e848cc6a3157b7bbe546117c76f.
    [MLC-1 - 4880K703-1.STL, MLC-1 - 4880K703-2.STL, MLC-1 - 4880K703-3.STL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]
2013-07-25 uploaded assembly in single stl
    [MLC-1.STL]
2013-07-25 updated assembly with new parts for scara arm
    [MLC-1-0016.SLDPRT, MLC-1-0017.SLDPRT, MLC-1-0018.SLDPRT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]
2013-07-25 Updated assembly STL
    added z axis drive plate to assy
    [MLC-1-0012.SLDPRT, MLC-1-0021.SLDPRT, MLC-1-0022.SLDPRT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]
2013-07-26 Uploaded 3d pdf of experimental backlash nut
2013-07-26 uploaded backlash nut stl's
    [MLC-1-023.STL, MLC-1-024.STL]
2013-07-26 UPLOADED NEW MODELS Z AXIS
    BACKLASH NUT ASSY, MODIFIED Z AXIS CARRIAGE, UPLOADED ASSY STL
    [9662K480.SLDPRT, MLC-1-001.SLDPRT, MLC-1-0021.SLDPRT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]
2013-07-26 MAIN ASSY UPLOAD
    EVERYTHING COMPLETE EXCEPT Z AXIS COUPLER AND EXTRUDER ASSY.
    [MLC-1-0010.SLDPRT, MLC-1-0017.SLDPRT, MLC-1-0022.SLDPRT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]
2013-07-27 WORM EXTRUDER START
    [LUHB.SLDPRT, MLCEX-1.SLDASM, NEMA17STEPPER.SLDPRT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]
2013-07-27 BOM UPDATE
    [MLC-1.SLDASM, MLC-2.SLDASM, MLC-3.SLDASM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]
2013-07-27 UPLOADED EXPLODED VIDEOS
    [MLC-1.SLDASM]
2013-07-27 STL'S ADDED TO FAB FOLDER
    NEW BACKLASH NUT ASSY , CLEANED UP SOME EXTRANEOUS FILES
    [9662K350.SLDPRT, MLC-1-0016.STL, MLC-1-0017.STL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]
2013-07-27 UPLOAD PDF'S FOR PRINTED PARTS
    [MLC-1-0010.SLDDRW, MLC-1-0010.SLDPRT, MLC-1-0012.SLDDRW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]
2013-07-27 ADDED MORE STL'S AND PDF'S
    TIGHTENING CAP FOR MORGAN HEAD AND ADDED THREADS TO MORGAN HEAD
    [MLC-1-0018.SLDDRW, MLC-1-0018.SLDPRT, MLC-1-0018.STL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]
2013-07-27 ADDED EXPLODE VIDEOS
    [MLC-1.SLDASM, MLC-3.SLDASM, MLC-6.SLDASM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]
2013-07-27 updated parasolid for 3dfile.io
    [MLC-1.SLDASM, MLC-1.x_b]
2013-07-28 UPLOADED JHEAD MODELS
    3DXML IS WORKING BEST FOR 3DFILE.IO EVERYTHING IS DISPLAYING CORRECTLY
    WHEN USING 3DXML EXPORT FROM SOLIDWORKS
    [JHEAD NOZZLE.SLDPRT, JHEAD.SLDPRT, MLC-1-0018.SLDPRT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]
2013-07-28 UPDATED MORGAN HEAD STL
    [MLC-1-0018.STL, MLC-1.x_b]
2013-07-28 ADDED DRAWING OF ARM ASSEMBLY
    [MLC-6.SLDASM, MLC-6.SLDDRW]
2013-07-29 UPDATE STL
    UPDATED STL'S TO IMPROVE PRINTABILITY, MODELED UNIVERSAL PLATE
    [MLC-1-0016.SLDPRT, MLC-1-0016.STL, MLC-1-0018.SLDPRT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]
2013-07-29 MODIFIED MORGAN HEAD
    STL'S FOR NEW MORGAN HEAD AND FILAMENT INSERT AND DRAWINGS FOR MORGAN
    HEAD ASSY WITH FILAMENT INSERT
    [MLC-1-0018.SLDPRT, MLC-1-0018.STL, MLC-1-030.SLDPRT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]
2013-07-29 INCREASED GAP ON MORGAN HEAD THREADS
    [MLC-1-0018.SLDPRT, MLC-1-0018.STL, MLC-1-030.STL]
2013-07-30 MODIFIED PRINT CAPS TO .2MM
    [MLC-1-0018.SLDPRT, MLC-1-0018.STL, MLCE-1-001.SLDPRT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]
2013-07-30 ADDED HARDWARE TO WORKING DIRECTORY
    [MLC-1.SLDASM, MLC-3.SLDASM, MLC-6.SLDASM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]
2013-07-30 ADDED MORE HARDWARE
    [MLC-6.SLDASM, continous stud_am.sldprt]
2013-07-30 CREATED DXF'S FOR TOP AND BOTTOM PLATES
    [MLC-1-001.DXF, MLC-1-001.SLDPRT, MLC-1-002.DXF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]
2013-07-31 ADDED PICS OF MORGAN HEAD PRINTED
2013-07-31 UPLOADED RANDY'S PRINT PICS
2013-08-01 ADDED PRINT CAP TO MLC-1-0020
    [MLC-1-0020.SLDPRT, MLC-1-0020.STL, MLC-1.SLDASM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]
2013-08-02 MODIFIED DXF FOR TOP AND BOTTOM PLATES
    [MLC-1-001.DXF, MLC-1-002.DXF]
2013-08-03 ASSEMBLY SAVED IN ALT POSITION
    [MLC-1-008.SLDPRT, MLC-1.SLDASM]
2013-08-04 MODIFIED FOR 3/4" COPPER
    MODIFIED DRIVE WHEEL AND THETA A ARM TO FIX BEARING AND 3/4" COPPER
    TUBING.
    [MLC-1-0019.SLDPRT, MLC-1-0019.STL, MLC-1-009.SLDPRT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]
2013-08-07 UPDATED MLC-1.0019 PDF
    ADDED CHANGES TO DRAWING OF PART. INCREASED DIA TO 22.2MM FOR 3/4" US
    COPPER TUBING.
    [MLC-1-0019.SLDDRW]
2013-08-08 added adapter stl
    [MLC-1-0029.STL, MLC-1.SLDASM]
2013-08-17 uploaded belt tensioner
    [MLC-1.SLDASM, belt stop.SLDPRT, belt stop.STL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]
2013-09-04 added hall effect brkt
    [hall_effect_sensor_holder.SLDPRT, hall_effect_sensor_holder.STL]
2013-09-09 updated assy
    [MLC-1.SLDASM, MLC-3.SLDASM, MLCE-50.SLDASM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]
2013-09-10 added heatbed
    [50mm riser-short.SLDPRT, 50mm riser.SLDPRT, MK2A Heatbed.SLDPRT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]
2013-09-11 heatbed base plate
    [HEATBED BASE PLATE.SLDPRT, MLC-1.SLDASM, MLC-3.SLDASM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]
2013-09-12 dxf for heatbed base plate
    [HEATBED BASE PLATE.DXF, HEATBED BASE PLATE.SLDPRT, MLC-1.SLDASM]
2013-09-13 added extruder
    [MLC-1.SLDASM, airtripper-extruder-v3.SLDPRT]
2013-09-14 modified base plate for manufacturing by hand
    doing shit by hand sux balls
    [HEATBED BASE PLATE.SLDDRW, HEATBED BASE PLATE.SLDPRT, MLC-1.SLDASM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]
2013-09-19 dual wheel extruder start
    [NEMA17STEPPER.SLDPRT, good extruder assy.SLDASM, h3216.SLDPRT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]
2013-10-12 upated distal psi arm for easier printing
    [MLC-1-0017.SLDPRT, SCARA-CAL.scad, SCARA-CAL.stl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]
2013-10-28 added spool roller and fan shroud
    [MLC-1.SLDASM, SCARA-CAL.SLDPRT, SPOOL ROLLER ASSY.SLDASM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]
